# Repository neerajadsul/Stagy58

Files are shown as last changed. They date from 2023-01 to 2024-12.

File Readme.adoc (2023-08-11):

= Ortho82Split Keyboard
This is the current design iteration which has 41 keys on each half in orthogonal matrix.

KiCAD 7 Render

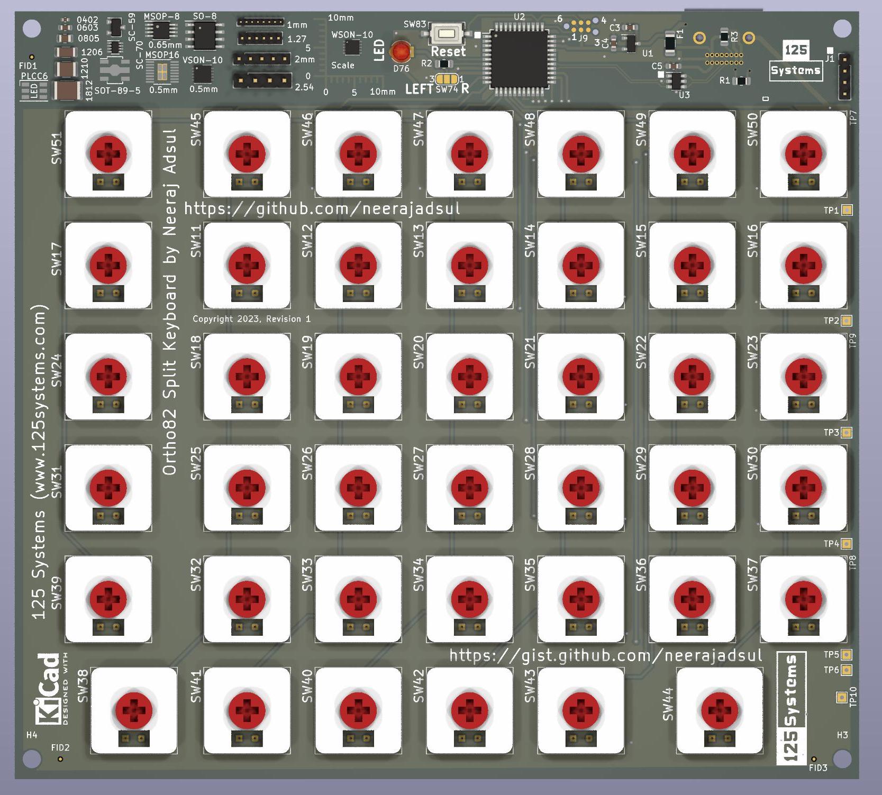
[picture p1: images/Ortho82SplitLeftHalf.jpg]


Fully assembled two halves of the keyboard, side by side

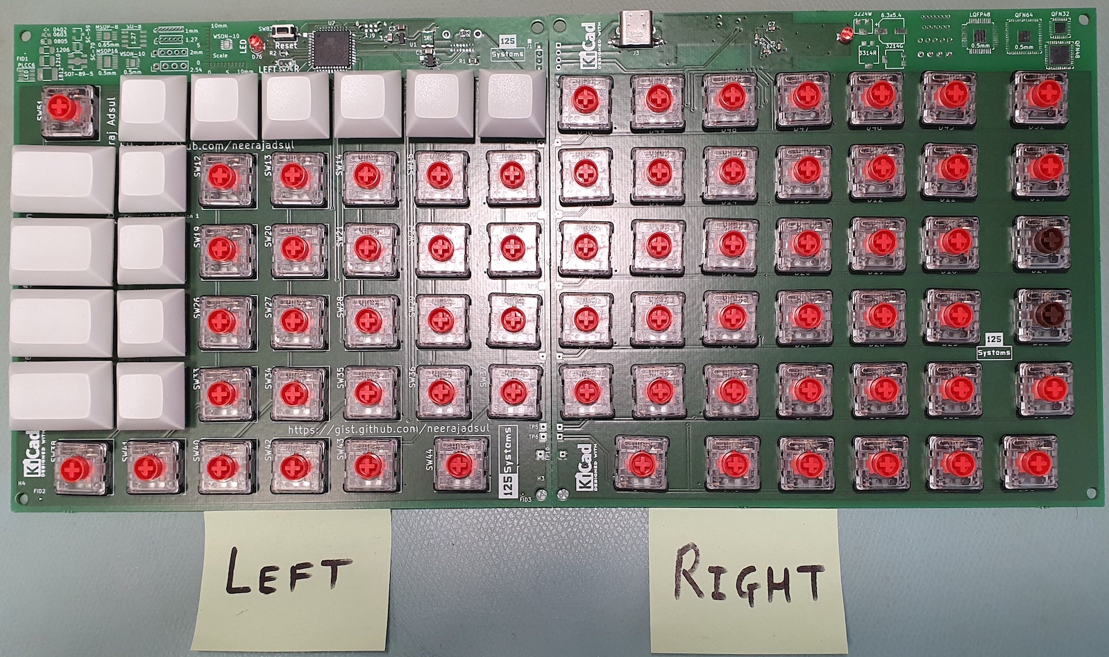
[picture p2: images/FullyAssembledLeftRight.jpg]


== Programmers Model

=== Row Signals to Microcontroller Pin

[cols="1,1,1"]
|===
| Signal | Pin | Keyboard Row

|ROW_F | PD0 | Esc, Function row
|ROW_0 | PD1 | Backtick, Numbers row
|ROW_1 | PD2 | Tab, QWERTY row
|ROW_2 | PD3 | Caps, ASDFG row
|ROW_3 | PD4 | Shift, ZXCVB row
|ROW_4 | PD5 | Ctrl, Fn, Opt, Cmd, Space row
|===

=== Column Signals to Microcontroller Pin
==== Left Half of the Split Keyboard
[cols="s,1,1,1,1,1,1,1"]
|===
|Signal | COL_0 | COL_1  | COL_2 | COL_3 | COL_4 | COL_5  | COL_6

| Pin | PC0 | PC1 | PC2 | PC3 | PC4 | PC5 | PC6 

|ROW_F | Esc | F1 | F2 | F3 | F4 | F5 | F6
|ROW_0 | ` (backtick) | 1 | 2 | 3 | 4 | 5 | 6
|ROW_1 | Tab | Q | W | E | R | T | Y
|ROW_2 | Caps | A | S | D | F | G | H
|ROW_3 | Shift | \ (backslash) | Z | X | C | V | B 
|ROW_4 | <NO KEY> | Ctrl  | MOD | Fn | Option | Cmd | Space | 
|===

==== Right Half of the Split Keyboard
[cols="s,1,1,1,1,1,1,1"]
|===
| Signal | COL_6 | COL_5  | COL_4 | COL_3 | COL_2 | COL_1  | COL_0
| Pin | PC6 | PC5 | PC4 | PC3 | PC2 | PC1 | PC0 

|ROW_F | F7 | F8 | F9 | F10 | F11 | F12 | Del
|ROW_0 | 7 | 8 | 9 | 0 | - | = | Backspace
|ROW_1 | U | I | O | P | [ | ] | Enter
|ROW_2 | J | K | L | ;: | '@ (quote) | # | Enter
|ROW_3 | N | M | ,< | .> | /? | UP | SHIFT 
|ROW_4 | Space | Cmd  | Option | LEFT | DOWN | RIGHT | <No Key> | 
|===

=== Communication between Left and Right Halves
Two halves of the split keyboard are connected by USART connection.
[cols="s,1,1"]
|===
| Signal | RXD0 | TXD0
| Pin | PE2 | PE3 
|===

=== Left/Right Half Identification and Indicator LED
Left and right are identified by setting a solder jumper on the board.
Left is 0 and right is 1.

[cols="s,1,1"]
|===
| Signal | Left-Right | Indicator LED
| Pin | PB2 | PB3 
|===

== Iterative Design History
I started with my TKL (tenkeyless) keyboard and tried to reduce the keys. 
I managed to reduce to 60 = 58 main + 2 extended keys for the keyboard.
This was partially inspired by Lily58 and other 60% keyboards avaialble. 
Also Kyria keyboard inspired me to customise the positions of the keys 
adapted to my hands and fingers. 
Following ficgure shows how I came up with draft with reduction in keys 
and logical positions in a worksheet. 

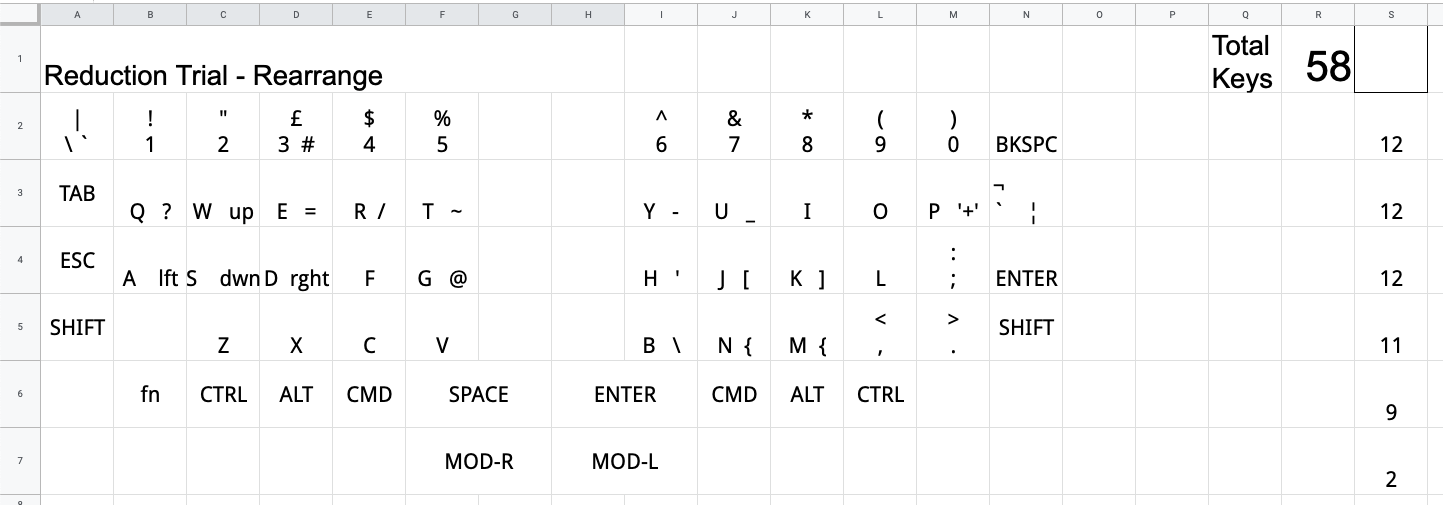
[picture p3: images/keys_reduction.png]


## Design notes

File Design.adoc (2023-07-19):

# Introduction
The goal of this document is to document design process for a split mechanical
keyboard using Macbook Pro keyboard as basis layout.
Macbook Pro keyboard (UK Layout) has following keys.

* Row-0    13  1 Esc, 12 Function keys
* Row-1    14  1 symbol, 10 numbers, Backspace
* Row-2    14  Tab, 10 letters, 2 symbols, half enter
* Row-3    14  CapsLock, 9 letters, 3 symbols, half enter
* Row-4    13  L-Shift, 7 letters, 4 symbols, R-shift
* Row-5    7   2 Cmd, 2 Alt, fn, Spacebar, Ctr

Total keys= 75

In additional there are
 - 4 Arrow keys

which makes it to 79 keys.
However, I decided to use combination of either _Mod + (H,J,K,L)_ or _Mod + (W,A,S,D)_
Also don't need the _fn_ key, 12 function keys can be added to a layer if really needed.
Caps Lock is only good for typewriters, and the corner key for tilda/backtick is maped to a layer.

So finally left with 79 - 4 - 1 - 12 - 1 - 1 = 60 keys.

## Layout
The layout was customised at keyboard-layout-editor.com as shown below.

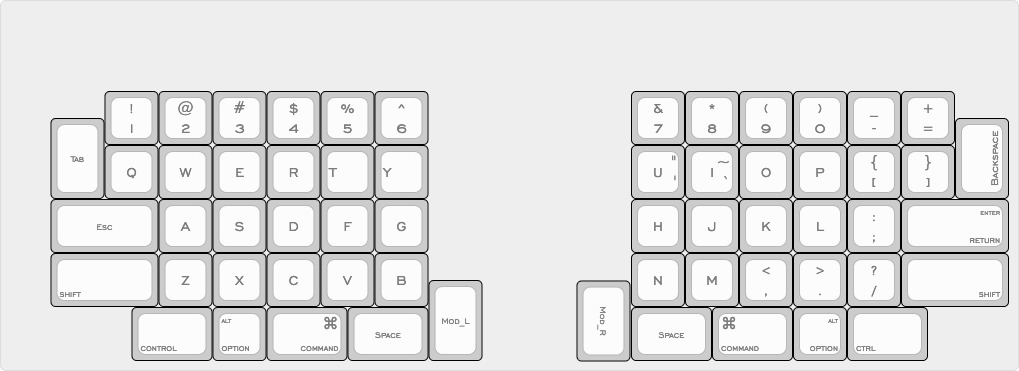
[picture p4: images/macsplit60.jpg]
MacSplit60 Layout


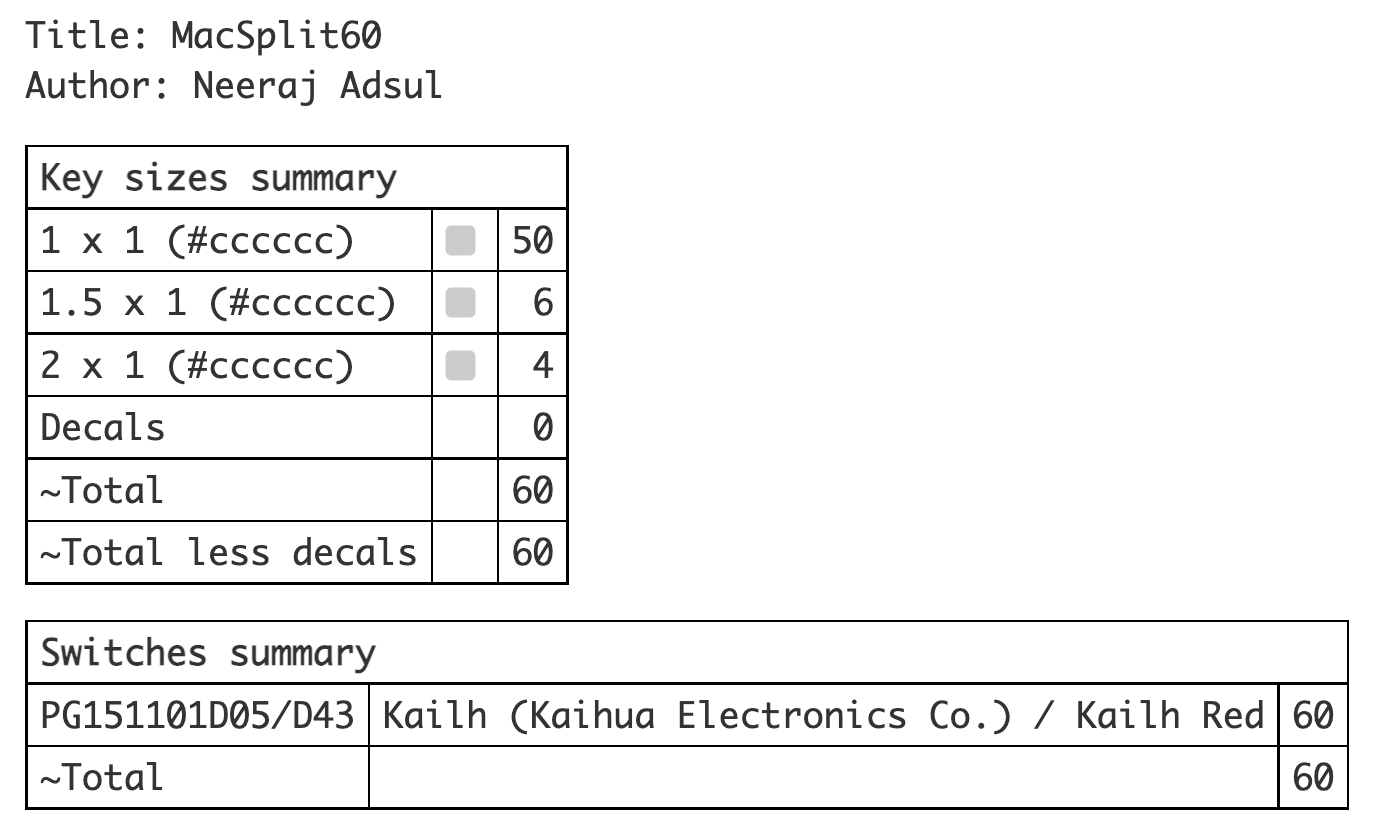
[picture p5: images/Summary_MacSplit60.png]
Summary of Switches


## Ortholinear Unified Keyboard

image::images/

### Mechanical Layout

* Row-0    14  1 symbol, 10 numbers, 2 symbols, Backspace
* Row-1    14  Tab, 10 letters, 2 symbols, 1 symbol
* Row-2    14  Escape, 9 letters, 3 symbols, EnterReturn
* Row-3    12  L-Shift, 7 letters, 3 symbols, R-shift
* Row-4    7   2 Cmd, 2 Alt, fn, Spacebar, Ctr

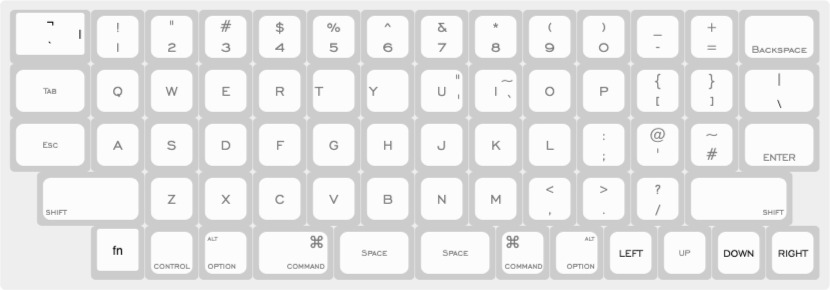
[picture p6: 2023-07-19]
Ortho62Unified/kbd_layout/ortho66unified.jpg

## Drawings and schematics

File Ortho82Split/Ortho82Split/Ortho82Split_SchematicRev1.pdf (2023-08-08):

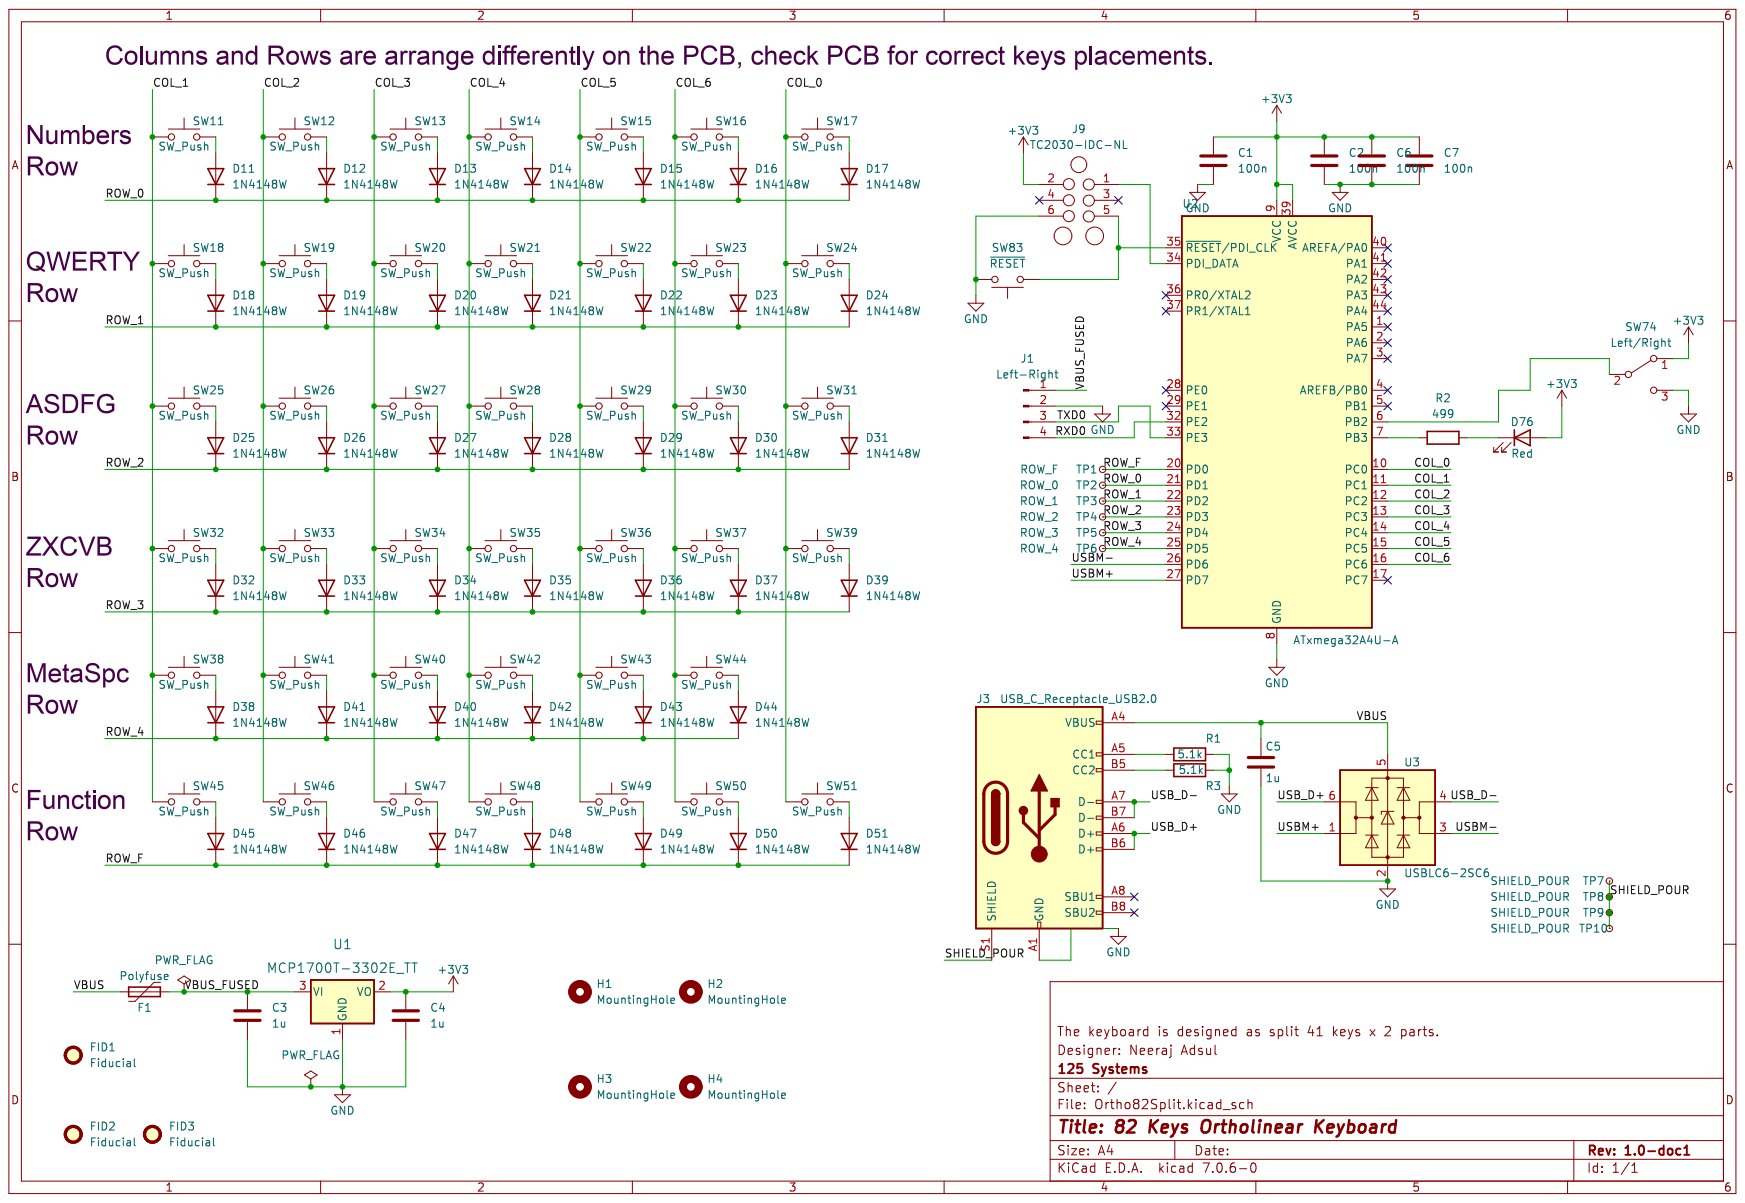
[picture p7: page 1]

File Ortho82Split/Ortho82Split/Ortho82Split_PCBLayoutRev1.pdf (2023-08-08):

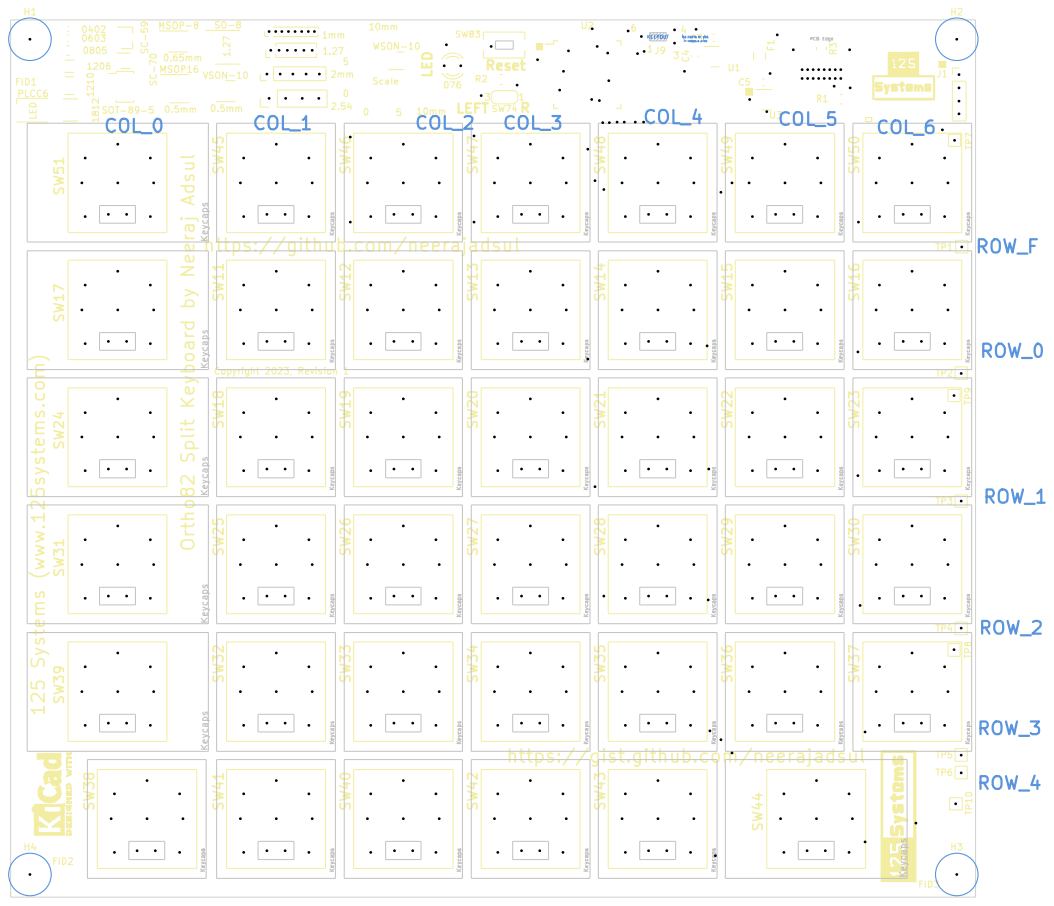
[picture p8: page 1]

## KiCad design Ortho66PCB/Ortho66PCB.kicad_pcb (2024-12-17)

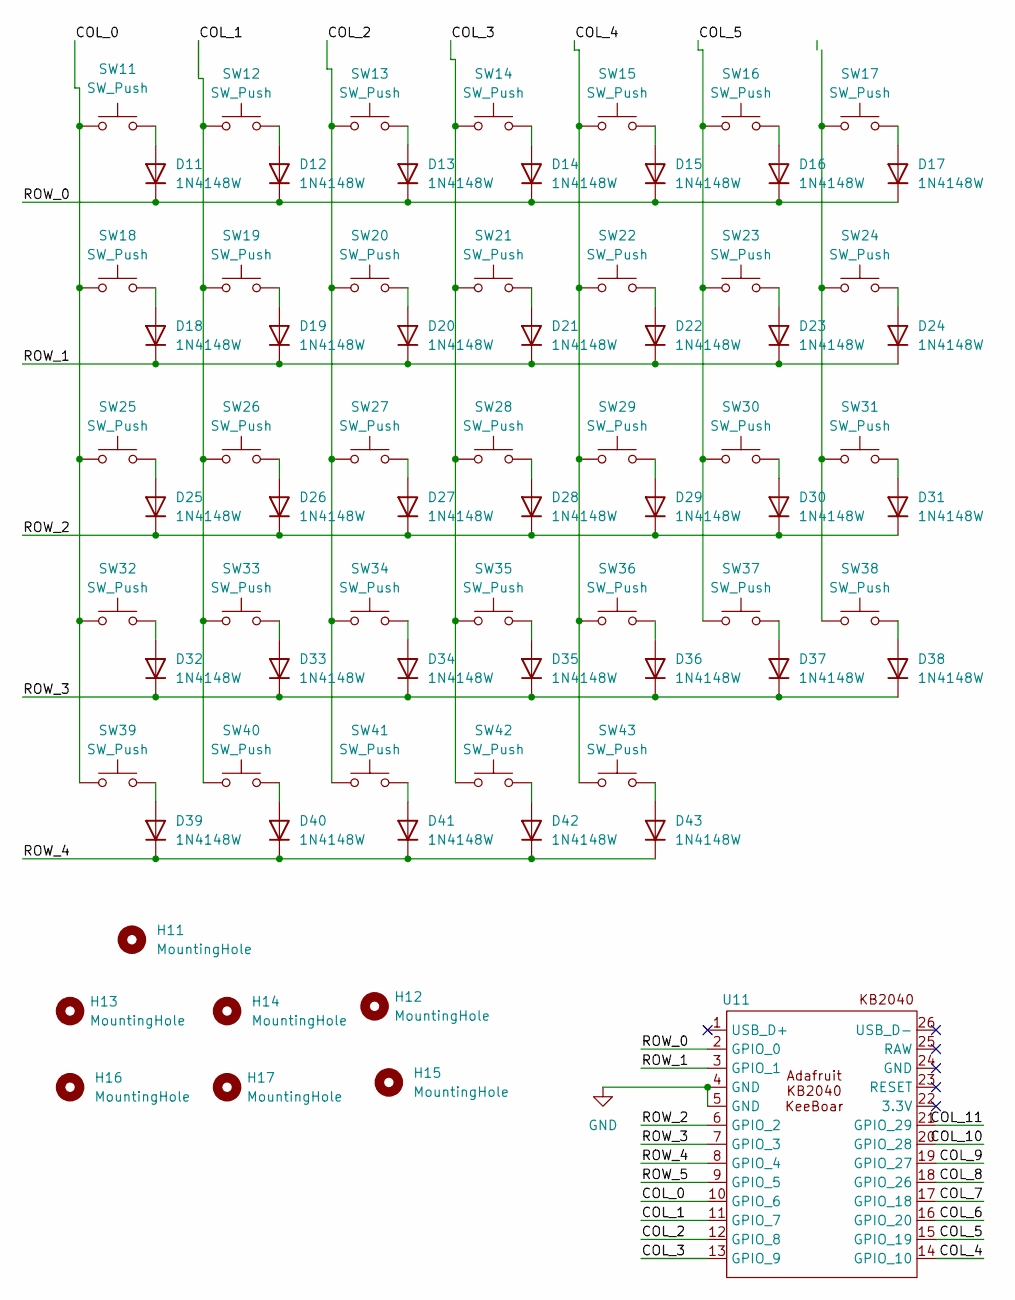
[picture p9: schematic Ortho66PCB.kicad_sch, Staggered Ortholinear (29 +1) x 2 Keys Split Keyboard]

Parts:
D11, D12, D13, D14, D15, D16, D17, D18, D19, D20, D21, D22, D23, D24, D25, D26, D27, D28, D29, D30, D31, D32, D33, D34, D35, D36, D37, D38, D39, D40, D41, D42, D43: 1N4148W; D_SOD-123
H11: MountingHole; MountingHole_2.7mm_M2.5
H12, H13, H14, H15, H16, H17: MountingHole; MountingHole_3.2mm_M3
SW11, SW18, SW25, SW32: SW_Push; SW_Kailh_Choc_V1V2_1.50u
SW12, SW13, SW14, SW15, SW16, SW17, SW19, SW20, SW21, SW22, SW23, SW24, SW26, SW27, SW28, SW29, SW30, SW31, SW33, SW34, SW35, SW36, SW37, SW38, SW39, SW40, SW42, SW43: SW_Push; SW_Kailh_Choc_V1V2_1.00u
SW41: SW_Push; SW_Kailh_Choc_V1V2_2.00u
U11: KB2040

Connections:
/COL_0: SW11.1, SW18.1, SW25.1, SW32.1, SW39.1, U11.10 (GPIO_6)
/COL_1: SW12.1, SW19.1, SW26.1, SW33.1, SW40.1, U11.11 (GPIO_7)
/COL_2: SW13.1, SW20.1, SW27.1, SW34.1, SW41.1, U11.12 (GPIO_8)
/COL_3: SW14.1, SW21.1, SW28.1, SW35.1, SW42.1, U11.13 (GPIO_9)
/COL_4: SW15.1, SW22.1, SW29.1, SW36.1, SW43.1, U11.14 (GPIO_10)
/COL_5: SW16.1, SW23.1, SW30.1, SW37.1, U11.15 (GPIO_19)
/COL_6: U11.16 (GPIO_20)
/COL_7: U11.17 (GPIO_18)
/COL_8: U11.18 (GPIO_26)
/COL_9: U11.19 (GPIO_27)
/COL_10: U11.20 (GPIO_28)
/COL_11: U11.21 (GPIO_29)
/ROW_0: D11.1 (K), D12.1 (K), D13.1 (K), D14.1 (K), D15.1 (K), D16.1 (K), D17.1 (K), U11.2 (GPIO_0)
/ROW_1: D18.1 (K), D19.1 (K), D20.1 (K), D21.1 (K), D22.1 (K), D23.1 (K), D24.1 (K), U11.3 (GPIO_1)
/ROW_2: D25.1 (K), D26.1 (K), D27.1 (K), D28.1 (K), D29.1 (K), D30.1 (K), D31.1 (K), U11.6 (GPIO_2)
/ROW_3: D32.1 (K), D33.1 (K), D34.1 (K), D35.1 (K), D36.1 (K), D37.1 (K), D38.1 (K), U11.7 (GPIO_3)
/ROW_4: D39.1 (K), D40.1 (K), D41.1 (K), D42.1 (K), D43.1 (K), U11.8 (GPIO_4)
/ROW_5: U11.9 (GPIO_5)
GND: U11.4 (GND), U11.5 (GND)
unnamed: D11.2 (A), SW11.2
unnamed: D12.2 (A), SW12.2
unnamed: D13.2 (A), SW13.2
unnamed: D14.2 (A), SW14.2
unnamed: D15.2 (A), SW15.2
unnamed: D16.2 (A), SW16.2
unnamed: D17.2 (A), SW17.2
unnamed: D18.2 (A), SW18.2
unnamed: D19.2 (A), SW19.2
unnamed: D20.2 (A), SW20.2
unnamed: D21.2 (A), SW21.2
unnamed: D22.2 (A), SW22.2
unnamed: D23.2 (A), SW23.2
unnamed: D24.2 (A), SW24.2
unnamed: D25.2 (A), SW25.2
unnamed: D26.2 (A), SW26.2
unnamed: D27.2 (A), SW27.2
unnamed: D28.2 (A), SW28.2
unnamed: D29.2 (A), SW29.2
unnamed: D30.2 (A), SW30.2
unnamed: D31.2 (A), SW31.2
unnamed: D32.2 (A), SW32.2
unnamed: D33.2 (A), SW33.2
unnamed: D34.2 (A), SW34.2
unnamed: D35.2 (A), SW35.2
unnamed: D36.2 (A), SW36.2
unnamed: D37.2 (A), SW37.2
unnamed: D38.2 (A), SW38.2
unnamed: D39.2 (A), SW39.2
unnamed: D40.2 (A), SW40.2
unnamed: D41.2 (A), SW41.2
unnamed: D42.2 (A), SW42.2
unnamed: D43.2 (A), SW43.2
unnamed: SW17.1, SW24.1, SW31.1, SW38.1

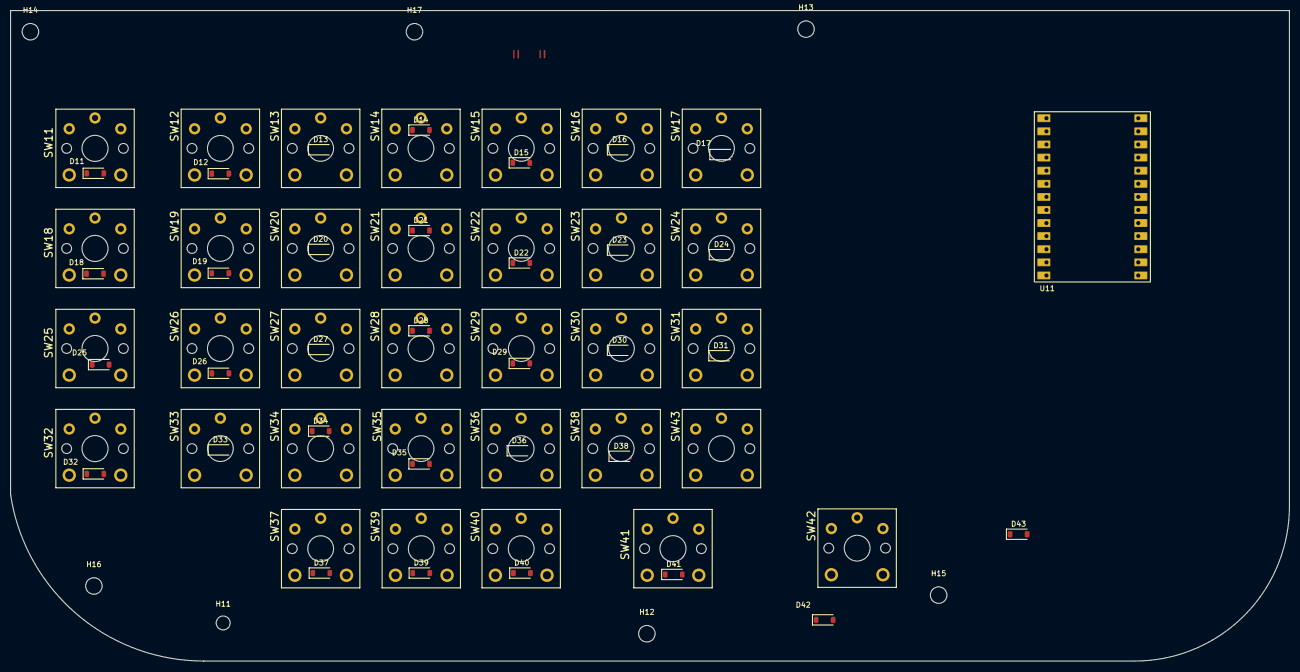
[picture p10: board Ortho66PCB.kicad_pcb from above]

Board: 2 copper layers, 247.9 x 126.1 mm, 74 parts (0 on the bottom side), 46 nets.

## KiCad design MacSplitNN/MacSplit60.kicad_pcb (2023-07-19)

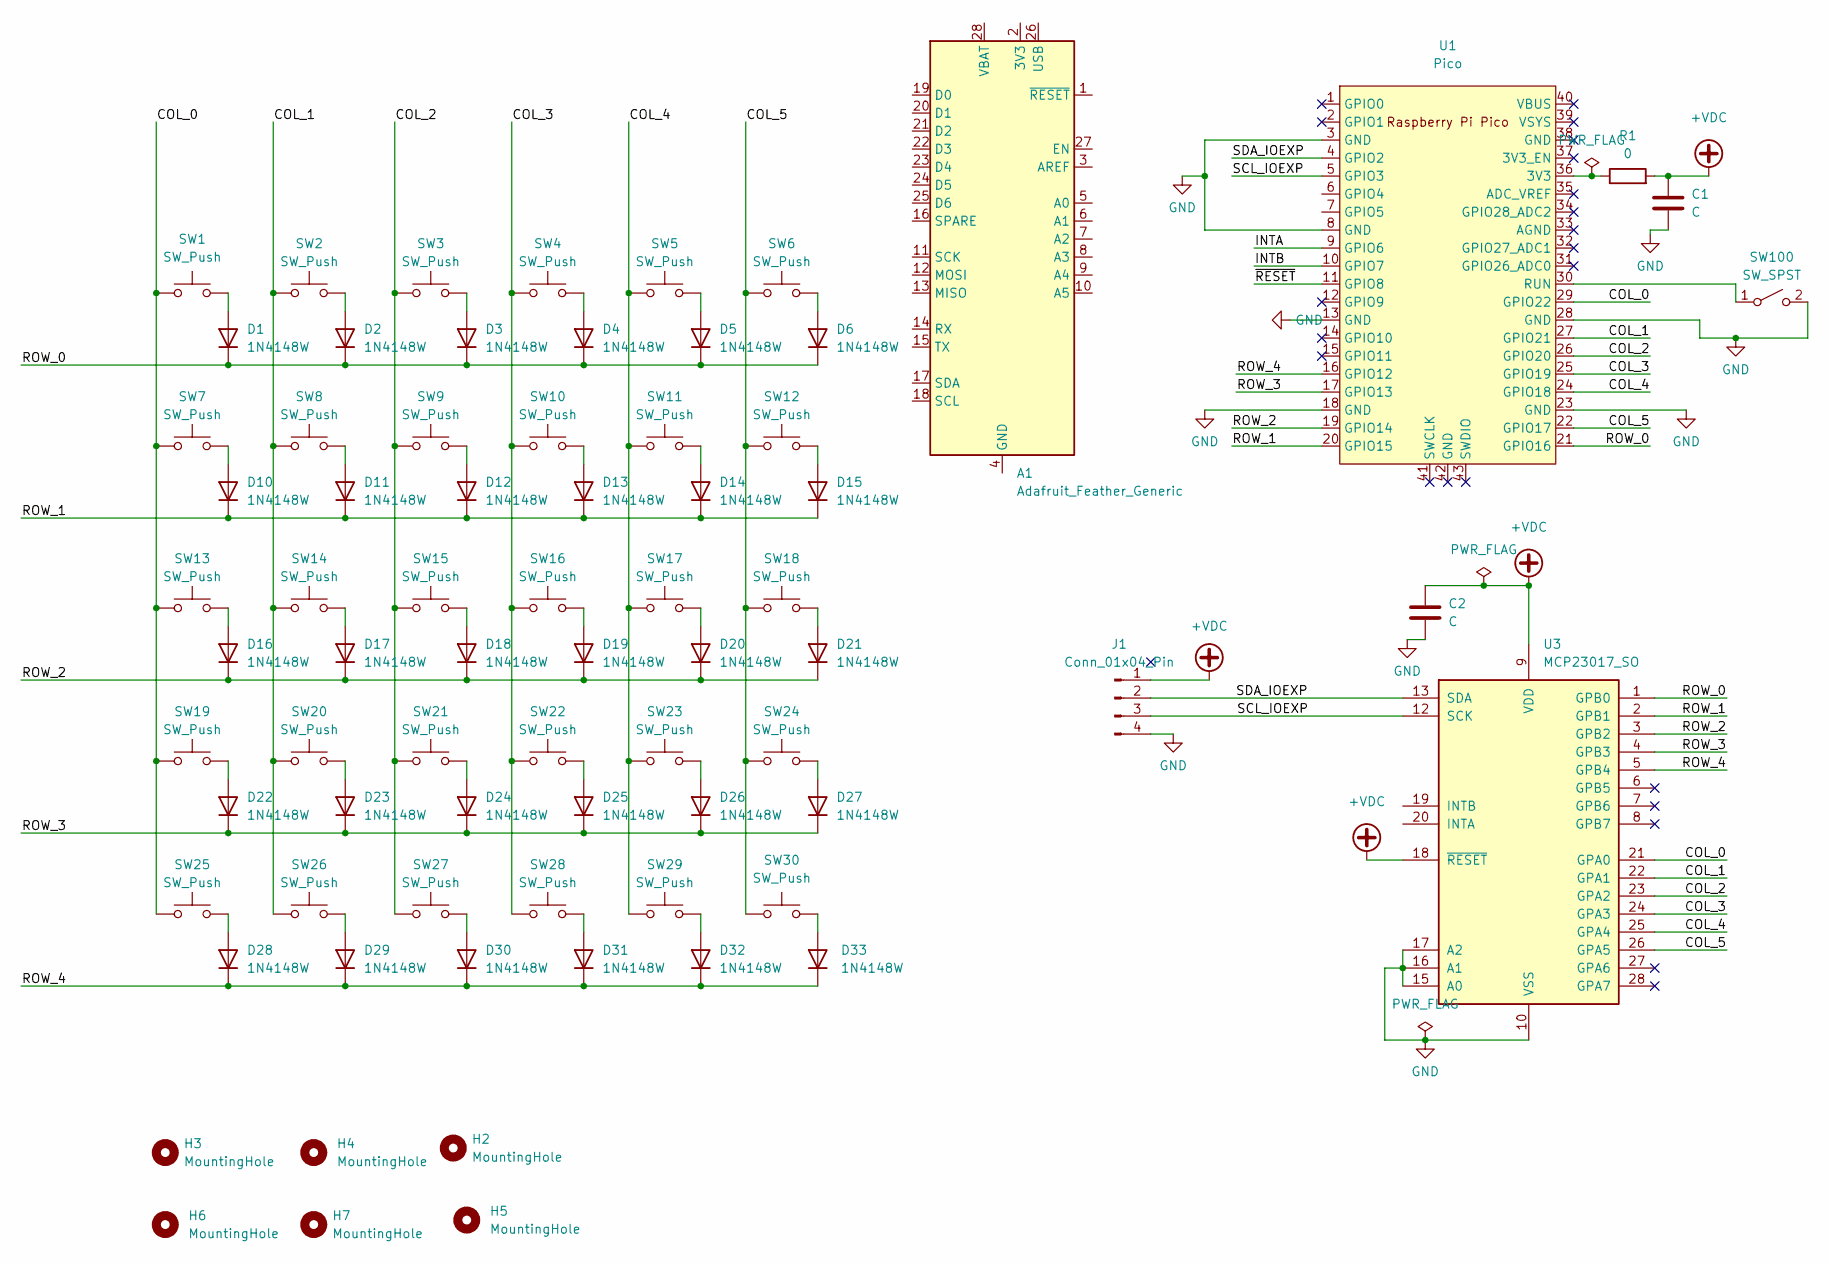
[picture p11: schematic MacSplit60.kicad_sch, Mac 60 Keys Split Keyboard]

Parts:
A1: Adafruit_Feather_Generic; Adafruit_Feather
C1, C2: C; C_0603_1608Metric
D1, D2, D3, D4, D5, D6, D10, D11, D12, D13, D14, D15, D16, D17, D18, D19, D20, D21, D22, D23, D24, D25, D26, D27, D28, D29, D30, D31, D32, D33: 1N4148W; D_SOD-323_Hand_Split_Keyboard
H2, H3, H4, H5, H6, H7: MountingHole; MountingHole_3.2mm_M3
J1: Conn_01x04_Pin; JST_PH_S4B-PH-SM4-TB_1x04-1MP_P2.00mm_Horizontal
R1: 0; R_0603_1608Metric_Pad0.98x0.95mm_HandSolder
SW1, SW2, SW3, SW4, SW5, SW6, SW7, SW8, SW9, SW10, SW11, SW12, SW14, SW15, SW16, SW17, SW18, SW20, SW21, SW22, SW23, SW24, SW25, SW26: SW_Push; SW_Kailh_Choc_V1V2_1.00u
SW13, SW19: SW_Push; SW_Kailh_Choc_V1V2_2.00u
SW27, SW28, SW29, SW30: SW_Push; SW_Kailh_Choc_V1V2_1.50u
SW100: SW_SPST; SW_SPST_CK_RS282G05A3
U1: Pico; RPi_Pico_SMD_TH
U3: MCP23017_SO; SOIC-28W_7.5x17.9mm_P1.27mm

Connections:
+VDC: C1.1, C2.1, J1.1, R1.2, U3.9 (VDD), U3.18 (~RESET)
/COL_0: SW1.1, SW7.1, SW13.1, SW19.1, SW25.1, U1.29 (GPIO22), U3.21 (GPA0)
/COL_1: SW2.1, SW8.1, SW14.1, SW20.1, SW26.1, U1.27 (GPIO21), U3.22 (GPA1)
/COL_2: SW3.1, SW9.1, SW15.1, SW21.1, SW27.1, U1.26 (GPIO20), U3.23 (GPA2)
/COL_3: SW4.1, SW10.1, SW16.1, SW22.1, SW28.1, U1.25 (GPIO19), U3.24 (GPA3)
/COL_4: SW5.1, SW11.1, SW17.1, SW23.1, SW29.1, U1.24 (GPIO18), U3.25 (GPA4)
/COL_5: SW6.1, SW12.1, SW18.1, SW24.1, SW30.1, U1.22 (GPIO17), U3.26 (GPA5)
/INTA: U1.9 (GPIO6)
/INTB: U1.10 (GPIO7)
/ROW_0: D1.1 (K), D2.1 (K), D3.1 (K), D4.1 (K), D5.1 (K), D6.1 (K), U1.21 (GPIO16), U3.1 (GPB0)
/ROW_1: D10.1 (K), D11.1 (K), D12.1 (K), D13.1 (K), D14.1 (K), D15.1 (K), U1.20 (GPIO15), U3.2 (GPB1)
/ROW_2: D16.1 (K), D17.1 (K), D18.1 (K), D19.1 (K), D20.1 (K), D21.1 (K), U1.19 (GPIO14), U3.3 (GPB2)
/ROW_3: D22.1 (K), D23.1 (K), D24.1 (K), D25.1 (K), D26.1 (K), D27.1 (K), U1.17 (GPIO13), U3.4 (GPB3)
/ROW_4: D28.1 (K), D29.1 (K), D30.1 (K), D31.1 (K), D32.1 (K), D33.1 (K), U1.16 (GPIO12), U3.5 (GPB4)
/SCL_IOEXP: J1.3, U1.5 (GPIO3), U3.12 (SCK)
/SDA_IOEXP: J1.2, U1.4 (GPIO2), U3.13 (SDA)
/~RESET: U1.11 (GPIO8)
GND: C1.2, C2.2, J1.4, SW100.2 (B), U1.3 (GND), U1.8 (GND), U1.13 (GND), U1.18 (GND), U1.23 (GND), U1.28 (GND), U3.10 (VSS), U3.15 (A0), U3.16 (A1), U3.17 (A2)
unnamed: D1.2 (A), SW1.2
unnamed: D2.2 (A), SW2.2
unnamed: D3.2 (A), SW3.2
unnamed: D4.2 (A), SW4.2
unnamed: D5.2 (A), SW5.2
unnamed: D6.2 (A), SW6.2
unnamed: D10.2 (A), SW7.2
unnamed: D11.2 (A), SW8.2
unnamed: D12.2 (A), SW9.2
unnamed: D13.2 (A), SW10.2
unnamed: D14.2 (A), SW11.2
unnamed: D15.2 (A), SW12.2
unnamed: D16.2 (A), SW13.2
unnamed: D17.2 (A), SW14.2
unnamed: D18.2 (A), SW15.2
unnamed: D19.2 (A), SW16.2
unnamed: D20.2 (A), SW17.2
unnamed: D21.2 (A), SW18.2
unnamed: D22.2 (A), SW19.2
unnamed: D23.2 (A), SW20.2
unnamed: D24.2 (A), SW21.2
unnamed: D25.2 (A), SW22.2
unnamed: D26.2 (A), SW23.2
unnamed: D27.2 (A), SW24.2
unnamed: D28.2 (A), SW25.2
unnamed: D29.2 (A), SW26.2
unnamed: D30.2 (A), SW27.2
unnamed: D31.2 (A), SW28.2
unnamed: D32.2 (A), SW29.2
unnamed: D33.2 (A), SW30.2
unnamed: SW100.1 (A), U1.30 (RUN)
unnamed: R1.1, U1.36 (3V3)

Board: 2 copper layers, 74 parts (32 on the bottom side), 47 nets, no tracks yet.

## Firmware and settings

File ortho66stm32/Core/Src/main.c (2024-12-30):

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
/* Includes ------------------------------------------------------------------*/
#include "main.h"
#include "usb_device.h"

SPI_HandleTypeDef hspi2;

TSC_HandleTypeDef htsc;

UART_HandleTypeDef huart1;

/* USER CODE BEGIN PV */
extern USBD_HandleTypeDef hUsbDeviceFS;
uint8_t HID_report[USBD_CUSTOMHID_OUTREPORT_BUF_SIZE] = {0};
/* USER CODE END PV */

void SystemClock_Config(void);
static void MX_GPIO_Init(void);
static void MX_SPI2_Init(void);
static void MX_TSC_Init(void);
static void MX_USART1_UART_Init(void);
/* USER CODE BEGIN 0 */
int __io_putchar(int ch)
{
  HAL_UART_Transmit(&huart1, (uint8_t *)&ch, 1, HAL_MAX_DELAY);
  return ch;
}
/* USER CODE END 0 */

/**
 * @brief  The application entry point.
 * @retval int
 */
int main(void)
{

  /* MCU Configuration--------------------------------------------------------*/

  /* Reset of all peripherals, Initializes the Flash interface and the Systick. */
  HAL_Init();

  /* Configure the system clock */
  SystemClock_Config();

  /* Initialize all configured peripherals */
  MX_GPIO_Init();
  MX_SPI2_Init();
  MX_TSC_Init();
  MX_USB_DEVICE_Init();
  MX_USART1_UART_Init();
  /* USER CODE BEGIN 2 */
  HAL_GPIO_WritePin(LD3_GPIO_Port, LD3_Pin, GPIO_PIN_SET);
  HAL_GPIO_WritePin(LD4_GPIO_Port, LD4_Pin, GPIO_PIN_SET);
  HAL_GPIO_WritePin(LD5_GPIO_Port, LD5_Pin, GPIO_PIN_SET);
  HAL_GPIO_WritePin(LD6_GPIO_Port, LD6_Pin, GPIO_PIN_SET);
  /* USER CODE END 2 */

  /* Infinite loop */
  /* USER CODE BEGIN WHILE */
  printf("Starting Loop!\n");
  uint32_t counter = 0;
  while (1)
  {
    /* USER CODE END WHILE */

    /* USER CODE BEGIN 3 */
    HAL_Delay(1000);
    printf("Loop %lu\n", counter++);
  }
  /* USER CODE END 3 */
}

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


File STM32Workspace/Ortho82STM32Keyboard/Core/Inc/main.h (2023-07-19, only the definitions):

#define USER_B1_Pin GPIO_PIN_13
#define USER_B1_GPIO_Port GPIOC
#define ROW_0_Pin GPIO_PIN_2
#define ROW_0_GPIO_Port GPIOC
#define ROW_1_Pin GPIO_PIN_3
#define ROW_1_GPIO_Port GPIOC
#define COL_0_Pin GPIO_PIN_1
#define COL_0_GPIO_Port GPIOB
#define COL_1_Pin GPIO_PIN_2
#define COL_1_GPIO_Port GPIOB
#define COL_2_Pin GPIO_PIN_11
#define COL_2_GPIO_Port GPIOB
#define COL_3_Pin GPIO_PIN_12
#define COL_3_GPIO_Port GPIOB
#define COL_4_Pin GPIO_PIN_13
#define COL_4_GPIO_Port GPIOB
#define COL_5_Pin GPIO_PIN_14
#define COL_5_GPIO_Port GPIOB
#define COL_6_Pin GPIO_PIN_15
#define COL_6_GPIO_Port GPIOB
#define ROW_2_Pin GPIO_PIN_6
#define ROW_2_GPIO_Port GPIOC
#define ROW_3_Pin GPIO_PIN_7
#define ROW_3_GPIO_Port GPIOC
#define ROW_4_Pin GPIO_PIN_8
#define ROW_4_GPIO_Port GPIOC

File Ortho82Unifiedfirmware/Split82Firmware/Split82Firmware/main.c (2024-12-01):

#include <atmel_start.h>
#include <util/delay.h>
#include <stdio.h>

#include "keymap.h"
#include "keycodes.h"
#include "version.h"

#define PRESSED		'P'
#define RELEASED	'R'


typedef struct {
	uint8_t key;
	uint8_t event;	
} Event_t;

void send_key_event(uint8_t key, uint8_t event);
int receive_key_event(Event_t* event);
void test_sequence();
void send_keys(HID_Keys_t*, char);
void init_keyboard_zeros(void);


void send_pressed_events(Keys_t *curr_keymap, HID_Keys_t *hid_keys, Keys_t prev_keymap, uint8_t is_left_half)
{
	for (uint8_t i=0; i < curr_keymap->count; i++) {	
		// Currently pressed keys
		uint8_t key = curr_keymap->keys[i];
		//uint8_t code;
		hid_keys->keys[i] = 0x00;
		if (!is_in_set(&prev_keymap, key)) {
			printf("%c 1 %d %s\n", is_left_half ? 'L':'R', key, get_key_id(key, is_left_half));
			USER_LED_toggle_level();
			send_key_event(key, PRESSED);
		}
	}
	
}

void send_released_events(Keys_t *prev_keymap, HID_Keys_t *hid_keys, Keys_t curr_keymap, uint8_t is_left_half)
{
	for (uint8_t i=0; i<prev_keymap->count ; i++)
	{
		// Released keys as they were previously pressed but not anymore
		uint8_t key = prev_keymap->keys[i];
		//uint8_t code;
		if (!is_in_set(&curr_keymap, key))
		{
			printf("%c 0 %d %s\n", is_left_half ? 'L':'R', key, get_key_id(key, is_left_half));
			USER_LED_toggle_level();
			send_key_event(key, RELEASED);
		}
	}
}

void process_other_half_events(Event_t *key_event)
{
	uint8_t ch = 0;
	key_event->key = 0;
	key_event->event = 0;

	if (receive_key_event(key_event))
	{
		if (key_event->event == PRESSED)
			ch = 1;
		else
			ch = 0;
		printf("L %d %d %s\n", key_event->event, key_event->key, get_key_id(key_event->key, false));
	}
}

int main(void)
{
	/* Initializes MCU, drivers and Middleware */
	PORTE.OUTSET = PIN3_bm;
	_delay_ms(100);
	atmel_start_init();
	// Send firmware version
	printf("Version: %s\n", get_semantic_version());
	static Keys_t prev_keymap;
	init_set(&prev_keymap);
	static Keys_t curr_keymap;
	static Event_t key_event;
	uint8_t is_left_half = IS_LEFT_get_level() ? 0 : 1;
	HID_Keys_t hid_keys = {.modifier=0x00, .keys={0,0,0,0,0,0}};
	printf("Is Left Half %d", is_left_half);
	_delay_ms(500);
	while (1) {
		init_set(&curr_keymap);
		keyboard_scan(&curr_keymap);
		send_pressed_events(&curr_keymap, &hid_keys, prev_keymap, is_left_half);
		send_released_events(&prev_keymap, &hid_keys, curr_keymap, is_left_half);
		init_set(&prev_keymap);
		copy_set(&curr_keymap, &prev_keymap);
		if (!is_left_half) {
			process_other_half_events(&key_event);
		}
	}
}


void send_key_event(uint8_t key, uint8_t event)
{
	USART_KBD_write('0' + (uint8_t)key/10);
	USART_KBD_write('0' + key%10);
	USART_KBD_write(':');
	if (event == PRESSED) {
		USART_KBD_write('1');
	} 
	else {
		USART_KBD_write('0');
	}
	USART_KBD_write('\n');
}


int receive_key_event(Event_t* event)
{
	uint8_t ch = 0;
	uint8_t packet_len = 0;
	uint8_t once = 0;
	
	while (USART_KBD_is_rx_ready())
	{
		ch = USART_KBD_read();
		if (ch == '\n') return 1;
		if (packet_len == 0)
		{
			event->key += (uint8_t)(ch - '0')*10;
		} else if (packet_len == 1) {
			event->key += (uint8_t)(ch - '0');
		} else if (packet_len == 3) {
			event->event = (uint8_t)(ch - '0');
		}
		packet_len++;
		//printf("%c", ch);
	}
	return 0;
}

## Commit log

2022-12-31 Blank Project
    [StagyOrtho58Hardware.kicad_pcb, StagyOrtho58Hardware.kicad_sch]
2022-12-31 30 push-button switches in schematic
    [StagyOrtho58Hardware.kicad_sch]
2022-12-31 Key switches matrix 6x5 with diodes
    [StagyOrtho58Hardware.kicad_sch]
2023-01-02 Adds ports expander and USB-C for split bridge
    [StagyOrtho58Hardware.kicad_pcb, StagyOrtho58Hardware.kicad_sch]
2023-01-02 Assigns inner 4x4 switches 1u footprints
    [StagyOrtho58Hardware.kicad_sch]
2023-01-02 Assigns Ctrl, Cmd, Alt switches 1.25u footprints
    [StagyOrtho58Hardware.kicad_sch]
2023-01-02 Working draft for key positions
    [StagyOrtho58Hardware.kicad_pcb, StagyOrtho58Hardware.kicad_sch]
2023-01-03 Comfortable positions of the keys, ready to layout
    [StagyOrtho58Hardware.kicad_pcb, StagyOrtho58Hardware.kicad_sch]
2023-01-03 Placed all components, board outline added
    [StagyOrtho58Hardware.kicad_pcb, StagyOrtho58Hardware.kicad_sch]
2023-01-03 Partial routing complete, approx 40%
    [StagyOrtho58Hardware.kicad_pcb, StagyOrtho58Hardware.kicad_sch]
2023-01-04 Routes rows, columns in switches
    [StagyOrtho58Hardware.kicad_pcb, StagyOrtho58Hardware.kicad_sch]
2023-01-04 Completes routing of the board
    [StagyOrtho58Hardware.kicad_pcb, StagyOrtho58Hardware.kicad_sch]
2023-01-05 Updated placement for switches as per MacSplit60
    [MacSplit60.kicad_pcb, MacSplit60.kicad_sch]
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2023-01-05 Updates switches positions according to MacSplit60 layout
    [MacSplit60.kicad_pcb, MacSplit60.kicad_sch]
2023-01-05 Corrects the PCB edge
    [MacSplit60.kicad_pcb]
2023-01-05 Equalises and checks switches spacing, diodes on both layers
    [MacSplit60.kicad_pcb, MacSplit60.kicad_sch]
2023-01-05 Completes routing of the PCB
    [MacSplit60.kicad_pcb]
2023-01-05 Generates interactive BOM
    [MacSplit60.kicad_pcb]
2023-01-06 Adds PCB design info to silkscreen, gerbers for production
    [MacSplit60-B_Cu.gbr, MacSplit60-B_Mask.gbr, MacSplit60-B_Paste.gbr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]
2023-01-09 Changes USB-C footprint to circular hole and pad
    [MacSplit60.kicad_pcb, MacSplit60.kicad_sch]
2023-01-10 simple rectangular block for USB-C connector
    [MacSplit60.kicad_pcb]
2023-01-10 Updates keyboard image with correct 3dModel for switch
    [MacSplit60.kicad_pcb]
2023-02-03 swap backspace and backslash
    [matrix_scan_keypad.py]
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2023-02-26 Prepare for unified ortholinear keyboard
    [Ortho62Unified.kicad_pcb, Ortho62Unified.kicad_sch]
2023-02-26 66 keys placed in a grid
    [Ortho62Unified.kicad_pcb, Ortho62Unified.kicad_sch]
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2023-02-27 66 keys in grid
    [Ortho62Unified.kicad_pcb, Ortho62Unified.kicad_sch]
2023-07-07 Connections for grid layout keys.
    [Ortho62Unified.kicad_pcb, Ortho62Unified.kicad_sch]
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2023-07-07 Save files in KiCad version 7 format.
    [Ortho62Unified.kicad_pcb, Ortho62Unified.kicad_sch]
2023-07-07 Rearrange keys, add AVR micro.
    [Ortho62Unified.kicad_pcb, Ortho62Unified.kicad_sch]
2023-07-10 66 symmetrical layout.
    [Ortho62Unified.kicad_pcb, Ortho62Unified.kicad_sch]
2023-07-10 Add cutout border for 3D visualisation
    [Ortho62Unified.kicad_pcb]
2023-07-12 Draft update - remove USB-C and IO Expander chip, unroute all.
    [MacSplit60.kicad_pcb, MacSplit60.kicad_sch]
2023-07-12 Align and correctly space 66 keys.
    [Ortho62Unified.kicad_pcb, Ortho62Unified.kicad_sch]
2023-07-13 Add function keys row.
    [Ortho62Unified.kicad_pcb, Ortho62Unified.kicad_sch]
2023-07-13 Place and align all 82 keys.
    [Ortho62Unified.kicad_pcb, Ortho62Unified.kicad_sch]
2023-07-13 Place all diodes within keys.
    [Ortho62Unified.kicad_pcb]
2023-07-13 Route rows and colums of keyboard matrix to 1.27mm headers.
    [Ortho62Unified.kicad_pcb, Ortho62Unified.kicad_sch]
2023-07-13 Consolitate and place Xmega and USB components.
    [Ortho62Unified.kicad_pcb, Ortho62Unified.kicad_sch]
2023-07-14 Remove F6,F7,F8 keys to create space for controller.
    [Ortho62Unified.kicad_pcb, Ortho62Unified.kicad_sch]
2023-07-14 Progress routing rows and columns.
    [Ortho62Unified.kicad_pcb, Ortho62Unified.kicad_sch]
2023-07-17 Routing complete for Xmega based design.
    [Ortho62Unified.kicad_pcb, Ortho62Unified.kicad_sch]
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2023-07-18 USB device descriptor enumration fails.
    [Ortho82STM32Keyboard.ioc, main.c]
2023-07-19 Add fiducials on PCB.
    [Ortho62Unified.kicad_pcb]
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2023-07-19 Add additional key in bottom row.
    [Ortho62Unified.kicad_sch]
2023-07-19 Makes bottom row with modifier keys symmetric.
    [Ortho62Unified.kicad_sch]
2023-07-19 Draft left half of split-keyboard.
    [Ortho82Split.kicad_pcb, Ortho82Split.kicad_sch]
2023-07-20 Corrects spacing between keyswitches.
    [Ortho82Split.kicad_pcb, Ortho82Split.kicad_sch]
2023-07-20 Route USB and xmega circuit.
    [Ortho82Split.kicad_pcb, Ortho82Split.kicad_sch]
2023-07-20 Routing complete.
    [Ortho82Split.kicad_pcb]
2023-07-20 Adds USB current resistors.
    [Ortho82Split.kicad_pcb, Ortho82Split.kicad_sch]
2023-07-21 Adds reference footprints in empty space.
    [Ortho82Split.kicad_pcb]
2023-07-21 Add 125 systems and KiCad Logos.
    [Ortho82Split.kicad_pcb]
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2023-08-04 Document and tidyup schematic.
    [Ortho82Split.kicad_pcb, Ortho82Split.kicad_sch]
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2023-08-06 Check oscillator ready, Red LED On on startup.
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2023-08-08 Update documentation on schematic and PCB.
    [Ortho82Split.kicad_pcb, Ortho82Split.kicad_sch]
2023-08-08 Correct right half scan map and send left or right configuration from main function.
    [main.c]
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2023-08-10 Correct modifier logic, detect modifiers and regular keys.
    [main.c]
2023-08-10 Final tryout, does not work, I give up with CodevisionAVR.
    [main.c]
2023-08-11 Ortho82 LUFA libary based trial. (#14)
    * Documentation update with photos of assembled keyboard.
    * Correct the formatting.
    * Example copied from LUFA low-level keyboard demo.
    * LUFA attempt, fails , probably problem with XMEGA devices support in LUFA.
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2023-08-11 Sort the second half of the keyboard, left side in this case.
2023-08-12 Restructure Keycode maps to avoid conditionals, clean logic to work as per USB connected half.
    [ortho82_split_keyboard.py]
2023-08-13 Correct the layout with British PC keycodes.
    [ortho82_split_keyboard.py]
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2024-11-16 Key events pressed and released.
    Need to fix sending pressed multiple times.
    [main.c]
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2024-11-17 Try sending Windows key, does not work.
    [main.c]
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2024-11-27 initial value TX(PE3) to high, avoid sending 0xFF on reset
    [main.c]
2024-11-27 Key press and release working, both UART polled, no 0xFF on reset.
    [main.c, usart_basic.c]
2024-11-29 Fix bug: modifier should be detected by actual key id not by code.
    Modifier and non-modifier share keycode. Therefore determining whether a key is a modifier or not should be based on key id on the keyboard layout.
    [main.c]
2024-11-29 Correct the UART to CH9823
    [main.c]
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2024-11-30 Fix processing of right half data and formatting to USB HID Processor.
    [main.c]
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2024-11-30 Real fix with decoding right side, Round Robin Interrupts for two USARTs were essential.
    [main.c]
2024-12-01 Swap the main side to right as it has better place for Xiao SAMD21
    [main.c]
2024-12-17 Correct spacing and kb2040 try.
    [Ortho62Unified.kicad_sch, Ortho82Split.kicad_pcb, Ortho82Split.kicad_sch]
2024-12-17 New trial with 66 keys layout.
    [Ortho66PCB.kicad_pcb, Ortho66PCB.kicad_sch]
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2024-12-30 correct format specifier for unsigned long (uint32_t)
    [main.c]
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

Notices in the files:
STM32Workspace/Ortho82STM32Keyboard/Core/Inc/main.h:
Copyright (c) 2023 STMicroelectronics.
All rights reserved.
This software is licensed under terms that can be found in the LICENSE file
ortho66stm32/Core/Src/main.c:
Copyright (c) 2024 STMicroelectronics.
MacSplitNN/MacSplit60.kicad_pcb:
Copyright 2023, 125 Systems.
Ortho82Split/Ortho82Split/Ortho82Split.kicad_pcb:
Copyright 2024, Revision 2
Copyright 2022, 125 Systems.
